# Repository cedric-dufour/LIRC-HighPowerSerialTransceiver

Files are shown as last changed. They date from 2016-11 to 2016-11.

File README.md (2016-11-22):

LIRC High-Power Serial Transceiver
==================================

This electronics project spawned from my need to blast Philips RC6 infrared
codes across my entire living room and remote control my existing Feller
Zeptrion [1] (house control) electric installation, with the help of the Linux
Infrared Remote Control (LIRC) [2].

Unfortunately, my existing USB dongle would not transmit RC6 codes while my
spare serial transmitter would lack the power to blast IR accross the entire
room.

I thus designed this High-Power Serial Transceiver with the following key
points in mind:

 1. high-power IR transmission, using an external power source such as the
    RS-232 12-volt "Power-over-System" provided by some card (e.g. Exsys
    44092-2 [3]) or using a 9-volt battery

 2. versatile IR reception, compatible with both 36/38kHz and 56kHz remotes

 3. indicator LED to monitor IR reception (and transmission)

 4. do-it-yourself using "off-the-shelf" standard components [4]

starting with the designs proposed by LIRC and its contributors:

   http://www.lirc.org/transmitters.html

   http://www.lirc.org/receivers.html

and using this opportunity to over-design some of the components, such as to
protect the high-power LEDs to be driven out of specifications by the full
range of potential RS-232 signals/voltages (using a high-pass input filter
and a two-transistors constant current source).

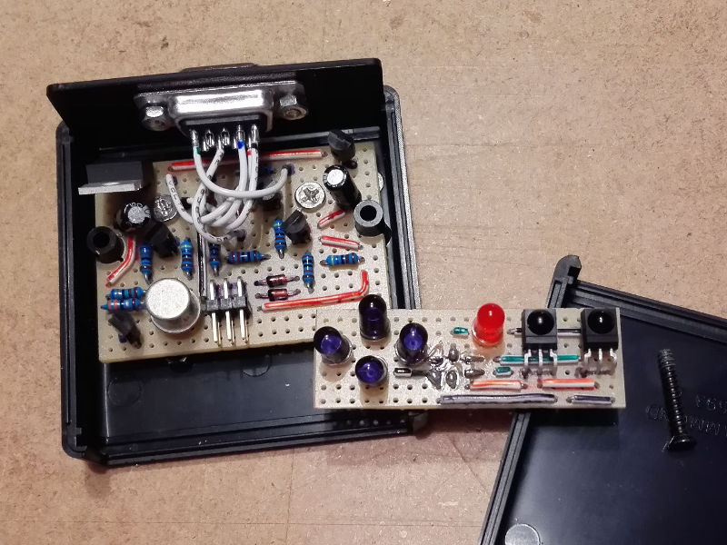
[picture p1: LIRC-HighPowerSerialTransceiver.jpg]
Overview Image
   

Provided files are:

 - KiCAD/Eeeschema schematic (and corresponding PDF plot)

 - KiCAD/PCBnew layout (and corresponding SVG export)

Please bear with me that the provided PCB layout is targeted towards 2.54mm-pad
rapid prototype boards rather than actual PCB manufacturing.

Enjoy!

References:

[1] https://www.feller.ch/de/Produktangebot/Licht-und-Storensteuerungssystem/Licht-Storensteuerung-zeptrion

[2] http://www.lirc.org

[3] http://www.exsys.de/index.php?page=product&info=202

[4] http://farnell.com

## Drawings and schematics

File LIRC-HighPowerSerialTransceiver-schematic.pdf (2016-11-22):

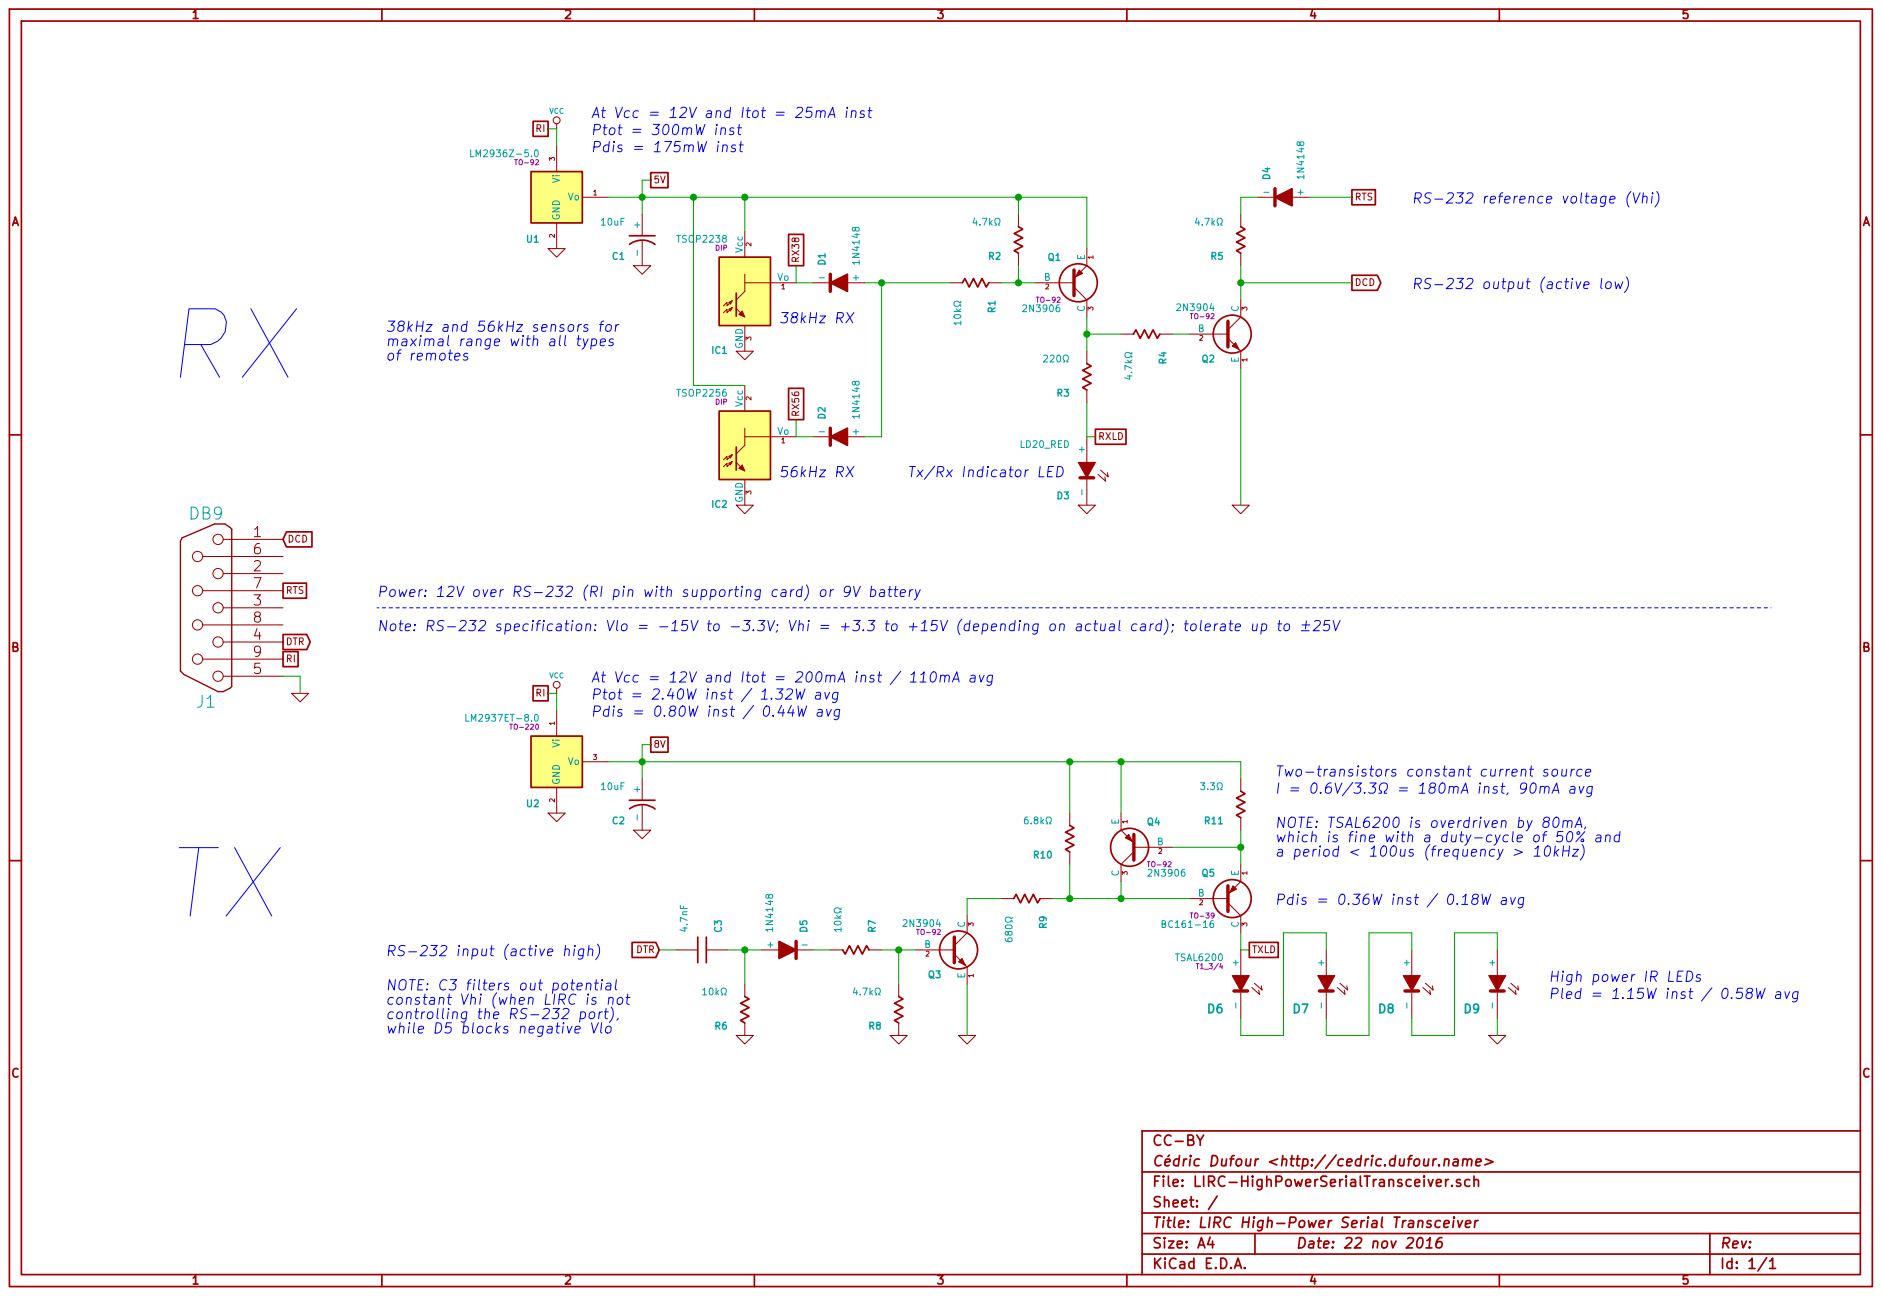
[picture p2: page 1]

Ptot = 2.40W inst / 1.32W avg Ptot = 300mW inst

RS-232 reference voltage (Vhi) VCC

RS-232 output (active low)

38kHz and 56kHz sensors for maximal range with all types of remotes

Note: RS-232 specification: Vlo = -15V to -3.3V; Vhi = +3.3 to +15V (depending on actual card); tolerate up to ±25V

NOTE: TSAL6200 is overdriven by 80mA,
which is fine with a duty-cycle of 50% and
a period < 100us (frequency > 10kHz)

RS-232 input (active high)

High power IR LEDs
Pled = 1.15W inst / 0.58W avg

controlling the RS-232 port),
while D5 blocks negative Vlo

Cédric Dufour <http://cedric.dufour.name>
File: LIRC-HighPowerSerialTransceiver.sch
Sheet: /
Title: LIRC High-Power Serial Transceiver

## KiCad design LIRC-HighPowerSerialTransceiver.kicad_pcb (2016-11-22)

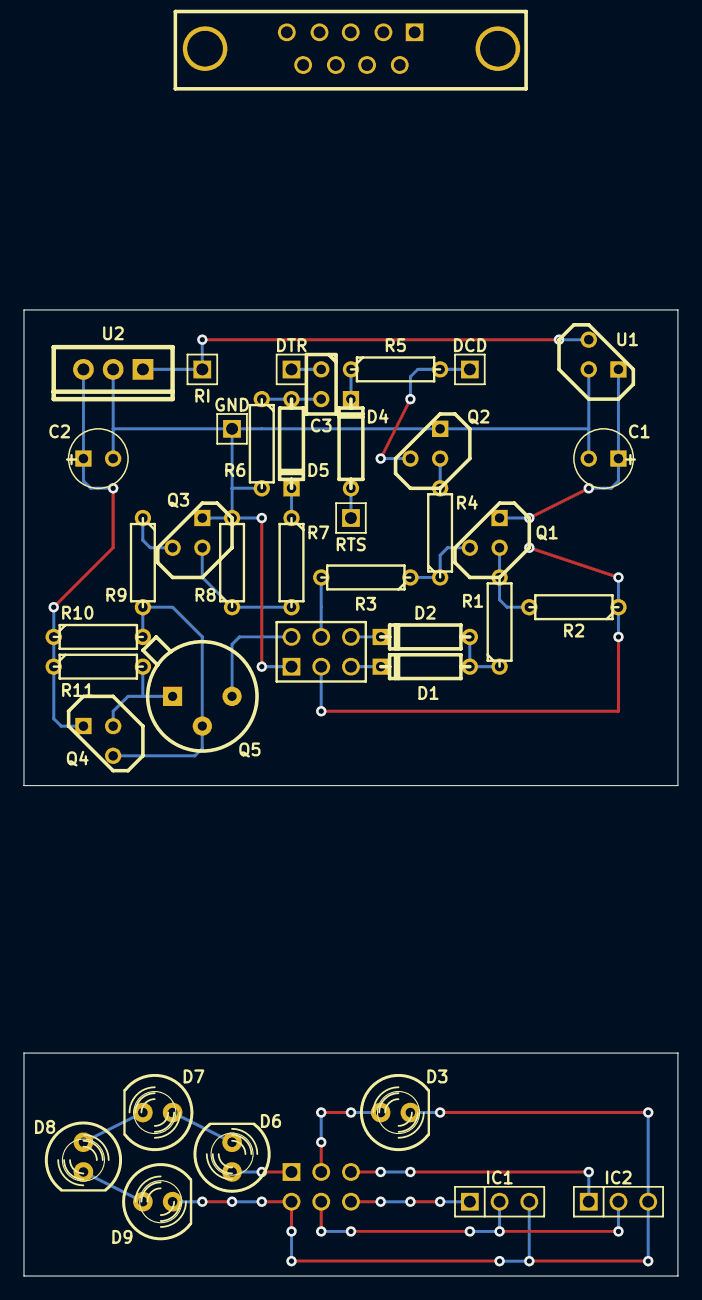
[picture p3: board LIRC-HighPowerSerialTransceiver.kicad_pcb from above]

Board: 2 copper layers, 55.9 x 82.6 mm, 40 parts (1 on the bottom side), 25 nets.

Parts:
C1, C2: 10uF; C1V5
C3: 4.7nF; C1
D1, D2, D4, D5: 1N4148; D3
D3: LD20_RED; LED-5MM
D6: TSAL6200; LED-5MM
D7, D8, D9: LED-5MM
DCD: Val**; PIN_ARRAY_1
DTR: Val**; PIN_ARRAY_1
GND: Val**; PIN_ARRAY_1
IC1: TSOP2238; PIN_ARRAY_3X1
IC2: TSOP2256; PIN_ARRAY_3X1
J1: DB9; DB9FD
PIN_ARRAY_3X2, PIN_ARRAY_3X2#2: Val**; pin_array_3x2
Q1, Q4: 2N3906; TO92-INVERT
Q2, Q3: 2N3904; TO92-INVERT
Q5: BC161-16; TO39EBC
R1, R6, R7: 10kΩ; R3
R2, R4, R5, R8: 4.7kΩ; R3
R3: 220Ω; R3
R9: 680Ω; R3
R10: 6.8kΩ; R3
R11: 3.3Ω; R3
RI: Val**; PIN_ARRAY_1
RTS: Val**; PIN_ARRAY_1
U1: LM2936Z-5.0; TO92-INVERT
U2: LM2937ET-8.0; TO220_123_VERT

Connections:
5V: C1.1, IC1.2, IC2.2, PIN_ARRAY_3X2.4, PIN_ARRAY_3X2#2.3, Q1.1, R2.1, U1.1
8V: C2.1, Q4.1, R10.1, R11.1, U2.3
DCD: DCD.1, J1.1, Q2.3, R5.2
DTR: C3.1, DTR.1, J1.4
GND: C1.2, C2.2, D3.2, D9.2, GND.1, IC1.3, IC2.3, J1.5, PIN_ARRAY_3X2.2, PIN_ARRAY_3X2#2.1, Q2.1, Q3.1, R6.2, R8.2, U1.2, U2.2
unnamed: D7.2, D8.1
unnamed: D8.2, D9.1
unnamed: D6.2, D7.1
unnamed: Q2.2, R4.2
unnamed: Q1.3, R3.1, R4.1
unnamed: D5.2, R7.1
unnamed: Q3.3, R9.1
unnamed: C3.2, D5.1, R6.1
unnamed: D4.2, R5.1
unnamed: Q4.2, Q5.1, R11.2
unnamed: Q4.3, Q5.2, R9.2, R10.2
unnamed: D1.1, D2.1, R1.1
unnamed: Q1.2, R1.2, R2.2
unnamed: Q3.2, R7.2, R8.1
RI: J1.9, RI.1, U1.3, U2.1
RTS: D4.1, J1.7, RTS.1
RX38: D1.2, IC1.1, PIN_ARRAY_3X2.6, PIN_ARRAY_3X2#2.5
RX56: D2.2, IC2.1, PIN_ARRAY_3X2.5, PIN_ARRAY_3X2#2.6
RXLD: D3.1, PIN_ARRAY_3X2.3, PIN_ARRAY_3X2#2.4, R3.2
TXLD: D6.1, PIN_ARRAY_3X2.1, PIN_ARRAY_3X2#2.2, Q5.3

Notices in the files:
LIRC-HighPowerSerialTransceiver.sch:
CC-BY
